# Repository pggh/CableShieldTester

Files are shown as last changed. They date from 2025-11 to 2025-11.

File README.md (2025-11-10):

# CableShieldTester

This is a simple build-it-yourself device that allows you to test
whether a cable is shielded or not. The device is easy and fast to use,
however, depending on the connector type you are dealing with, you need
a connector or adapter to get access to the signal lines.
There must be nothing connected to the other side of the cable.

The design is based on an ATtiny84 micro-controller so you will need a
programmer for it to build your device. (Any of the ATtiny24, ATtiny24A,
ATtiny44, ATtiny44A, ATtiny84, ATtiny84A will work.)

This video shows the test of an unshielded cable (**play with sound!**):

https://github.com/user-attachments/assets/809c1926-0d2f-4c97-92ae-36a32c1142be

More tests can be found [here](doc).

Build instructions are in the [hardware directory](hardware).

Discus at the [EEVblog Forum](https://www.eevblog.com/forum/projects/cableshieldtester-is-the-cable-shielded-or-not-(diy-project)/msg6097537/)

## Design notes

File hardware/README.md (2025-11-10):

# Hardware build instructions

There are two sets of schematics and PCBs:

- [template](template) contains the files you can use as a start
  to build your own device. The schematics and layout does not contain
  the power section, so you can choose what is suitable for your
  needs.  
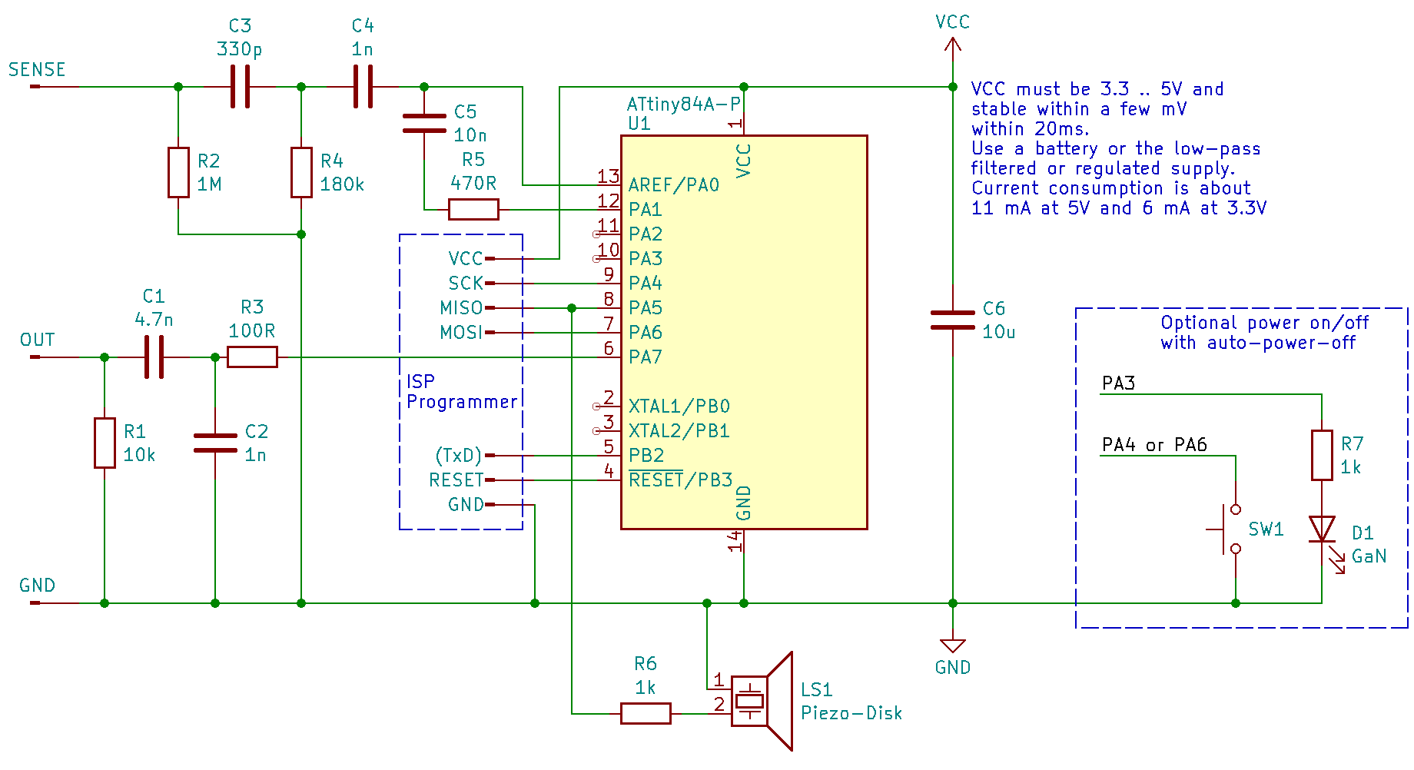
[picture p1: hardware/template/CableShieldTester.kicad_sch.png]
  [](template/CableShieldTester.kicad_sch.png)\
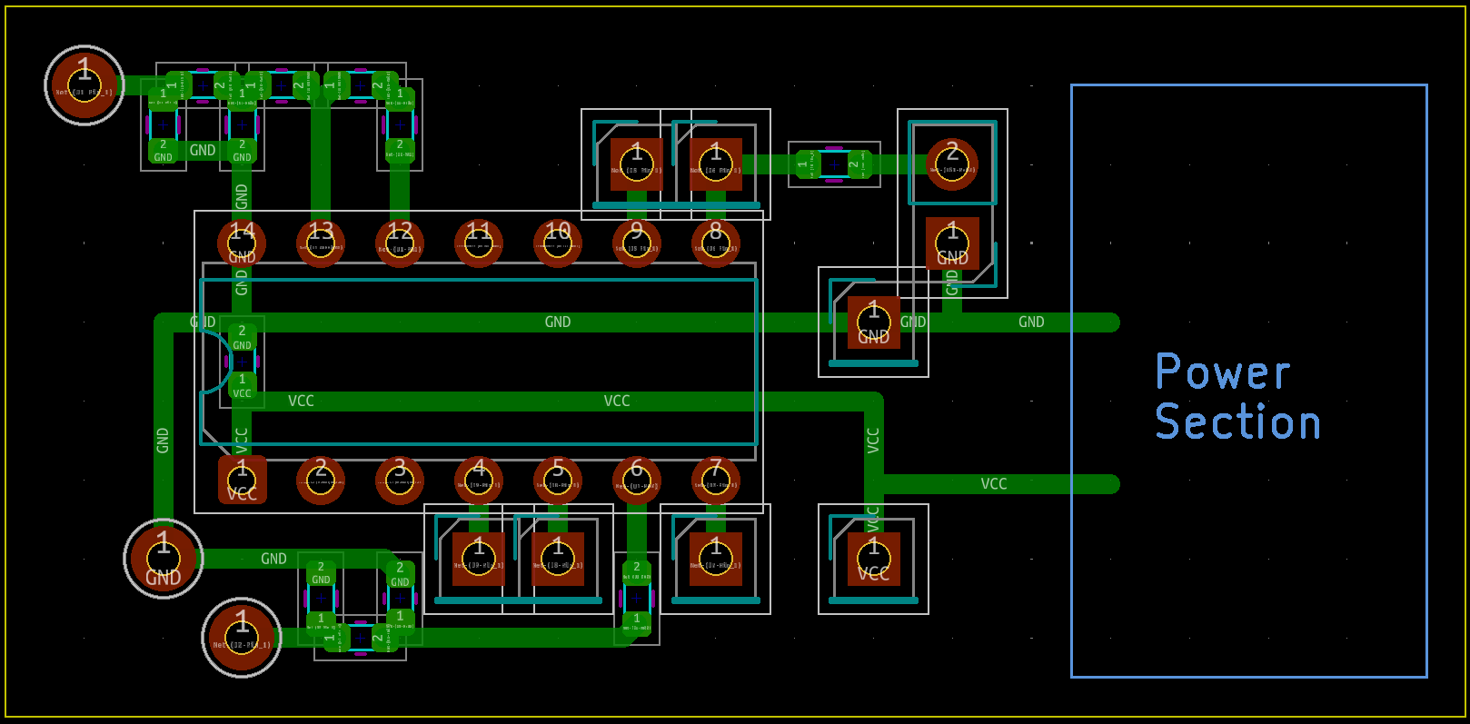
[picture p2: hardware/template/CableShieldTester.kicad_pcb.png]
  [](template/CableShieldTester.kicad_pcb.png)
- [my_build](my_build) contains the full schematics and layout of what I actually
  built for myself as a reference.  
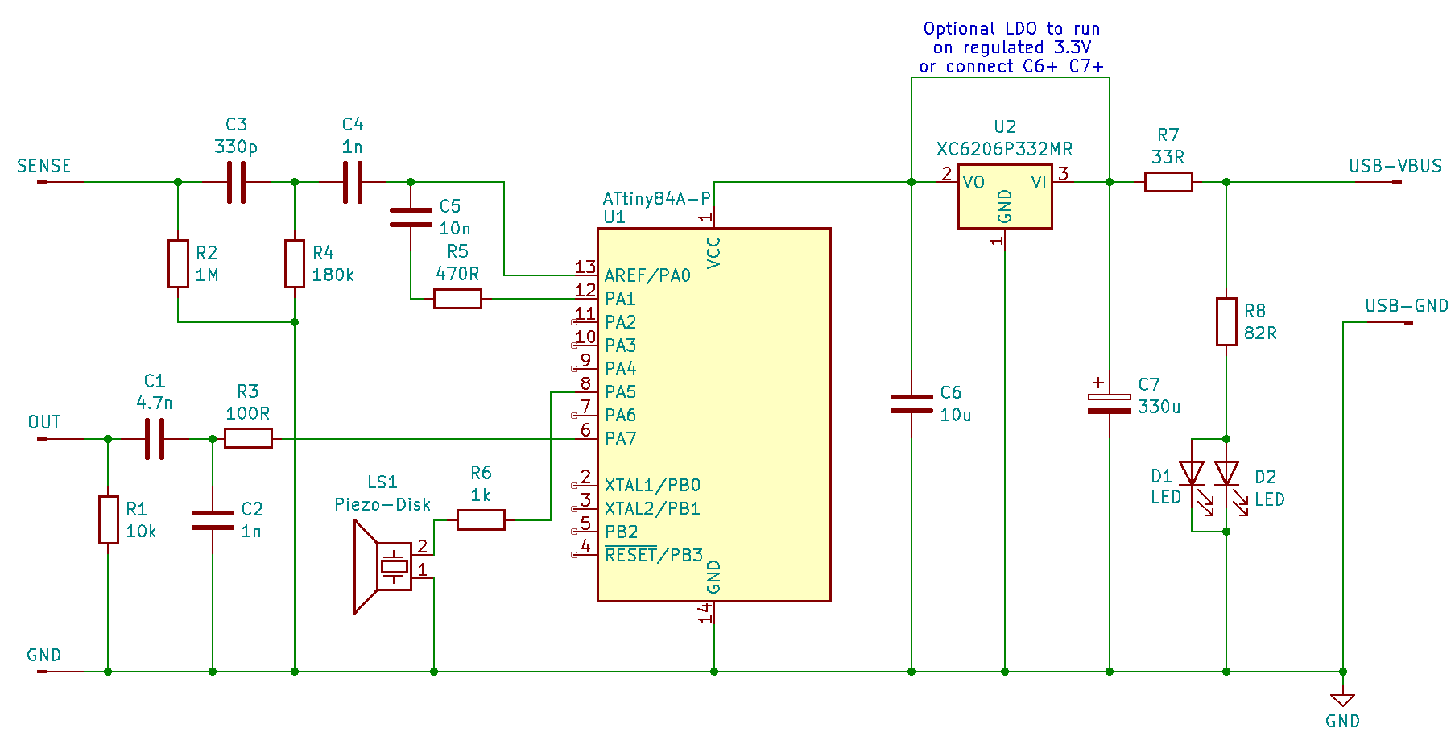
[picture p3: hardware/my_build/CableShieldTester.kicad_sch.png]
  [](my_build/CableShieldTester.kicad_sch.png)\
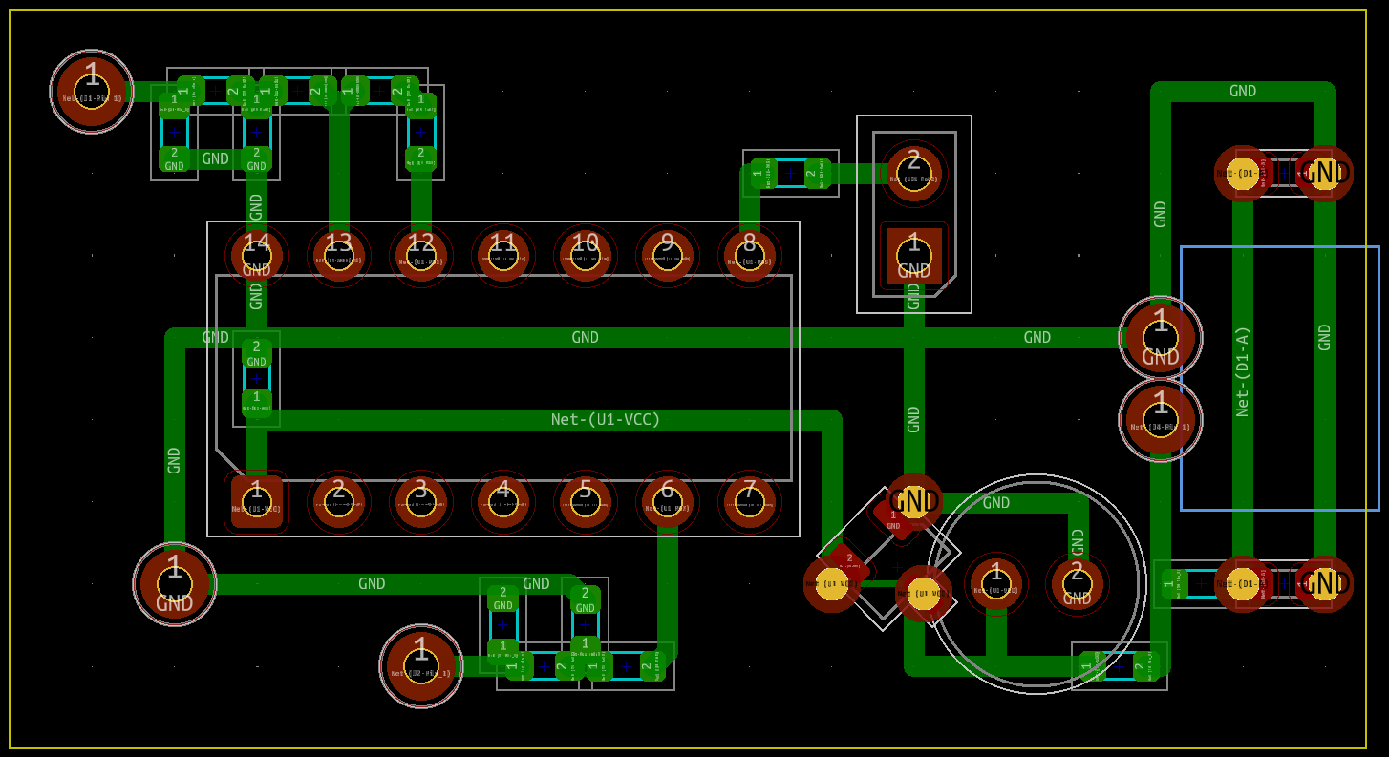
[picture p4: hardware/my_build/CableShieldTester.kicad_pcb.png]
  [](my_build/CableShieldTester.kicad_pcb.png)\
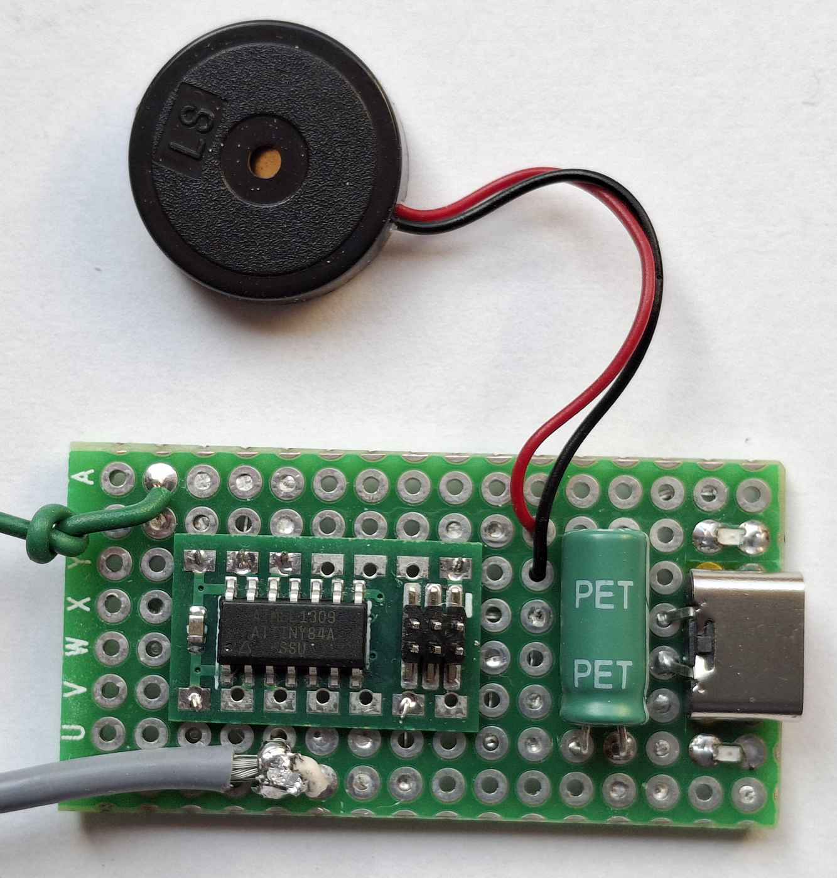
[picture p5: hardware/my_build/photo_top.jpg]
  [](my_build/photo_top.jpg)\
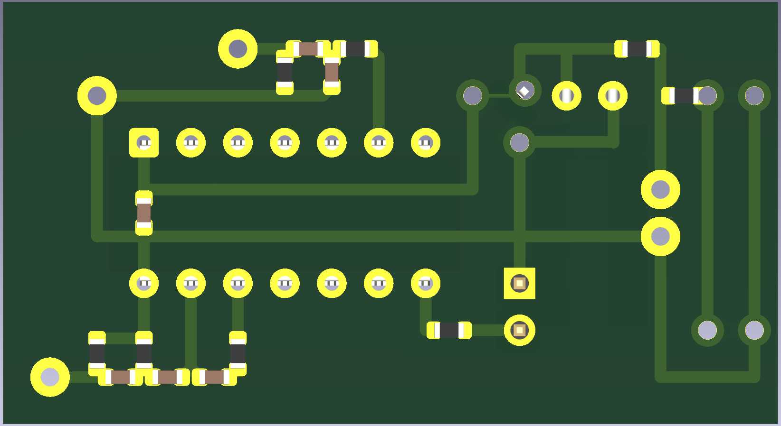
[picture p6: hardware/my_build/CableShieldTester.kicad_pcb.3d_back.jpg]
PCB back
  [](my_build/CableShieldTester.kicad_pcb.3d_back.jpg)\
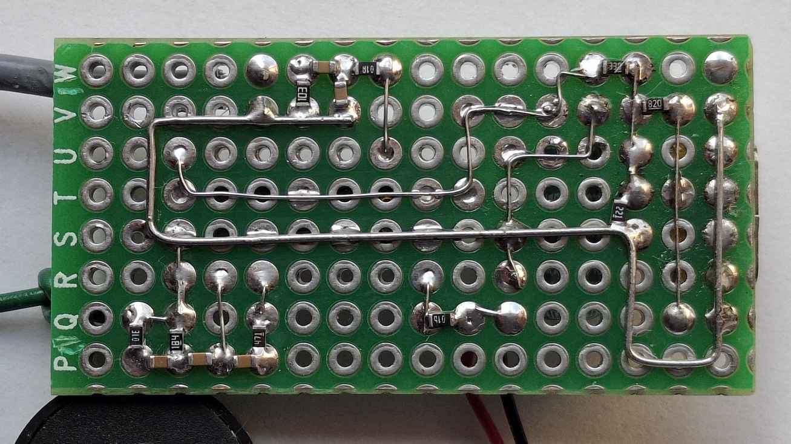
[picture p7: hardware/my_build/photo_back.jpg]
  [](my_build/photo_back.jpg)\
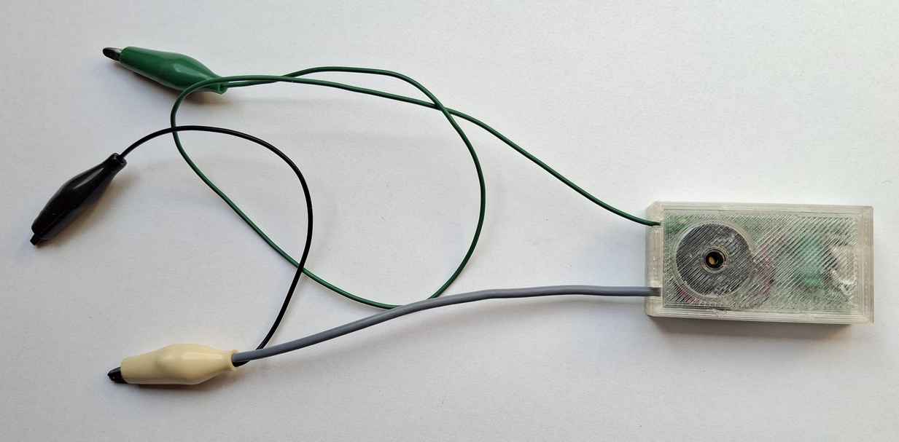
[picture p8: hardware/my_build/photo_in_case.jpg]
  [](my_build/photo_in_case.jpg)

# Layout and cables

- Keep output components and connection close to the Pin 6 and away form
  sense input.
- Use a shielded cable for the output signal. The shield (connected to
  GND) should go as close to the output components and the external
  output clip as possible. The GND clip can be connected to either side
  of the shield of the output cable.
- Keep sense input components and connection close to the input pins.
- Use a unshielded cable for the sense input to keep the input capacity
  low.

# Powering

The power source is critical. Due to the measurement principle of the
device, VCC must be rather stable within a measurement cycle of 20ms.

The ideal power source is a battery. A 3.6V lithium battery (non
rechargeable or rechargeable) or 3 AAA cells (alkaline or NiMH)

When using external power, the source should not have much ripple and a
proper voltage regulation. Many cheap USB chargers fail in both
disciplines. Also the power source must not have any mains common-mode
signal. Use either a power-bank or a mains power supply that has an
earth referenced output.

The usual 2 pin (mains) chargers have a Y2 capacitor from the mains to
the GND of the output and therefore a common-mode 50/60Hz signal of up
to 300Vpp. This is not acceptable for the high impedance measurement of
the cable tester and might even damage it.

When using power-banks, practically all modern ones require a minimal
load to stay on. I tested my build (consumes 43 mA with the two LEDs)
with 4 different power-banks a the current was sufficient for two of them
to stay on but not for the other two.

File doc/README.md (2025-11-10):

# Measurement examples

**Important: play all videos with sound - the measurement result is acoustical.**

## An unshielded audio cable

The ground pin is already connected. When the signal is applied to one of the audio lines, it is coupled to the sense line.

https://github.com/user-attachments/assets/809c1926-0d2f-4c97-92ae-36a32c1142be

## A shielded audio cable

The ground pin is already connected. When the signal is applied to one of the audio lines, nothing happens because the signal is shielded.

https://github.com/user-attachments/assets/3892af2c-89ef-467d-8cf5-392d25709fa2

## Common shield for both channels

The ground pin as well as the signal pin are already connected.
When connecting the sense input to the other audio channel, the signal is heavily coupled to it.

https://github.com/user-attachments/assets/de1b4ab3-1894-417e-95cb-727351e04f2a

## Individual shield for both channels

The ground pin as well as the signal pin are already connected.
When connecting the sense input to the other audio channel, the signal is slightly coupled to it.
Ideally no signal should leak through. The slight coupling could be within the connector or the shield is not that great.

https://github.com/user-attachments/assets/d68851f2-6222-4acf-88ee-22f93a323d15

## Unshielded USB cable

The signal pin is already connected to one of the USB signals. It is coupled to the sense line.
The coupling is not stopped, when connecting ground line to the shell of the connector.

https://github.com/user-attachments/assets/f3afa772-5d94-4523-8f89-95132691fe7d

## Shielded USB cable

The signal pin is already connected to one of the USB signals. It is coupled to the sense line.
When connecting the ground line to the shell of the connector, the signal coupling stops.

https://github.com/user-attachments/assets/339036e9-0693-466c-8054-61548ad63745

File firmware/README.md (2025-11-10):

# Firmware

This folder contains the sources and project files of the firmware.
It is meant to be compiled with 
[Atmel Studio / Microchip Studio for AVR](https://www.microchip.com/en-us/tools-resources/develop/microchip-studio#Downloads).
No particular framework is used, just the
[avr-libc](https://www.nongnu.org/avr-libc/user-manual/)
that comes with the AVR-GCC, so it should be possible to compile it
with other IDEs without much porting effort.

If you don't need any change, you can program the supplied
[.hex file](Release/CableShieldTester.hex)
and you don't need any compiler at all.

Many modification can be achieved by changing the definitions in
config.h. (Always use Release and not Debug builds)

Whether you use the supplied .hex file or you compile yourself,
I suggest that you set BOD fuses of the chip to a level of 2.7V.

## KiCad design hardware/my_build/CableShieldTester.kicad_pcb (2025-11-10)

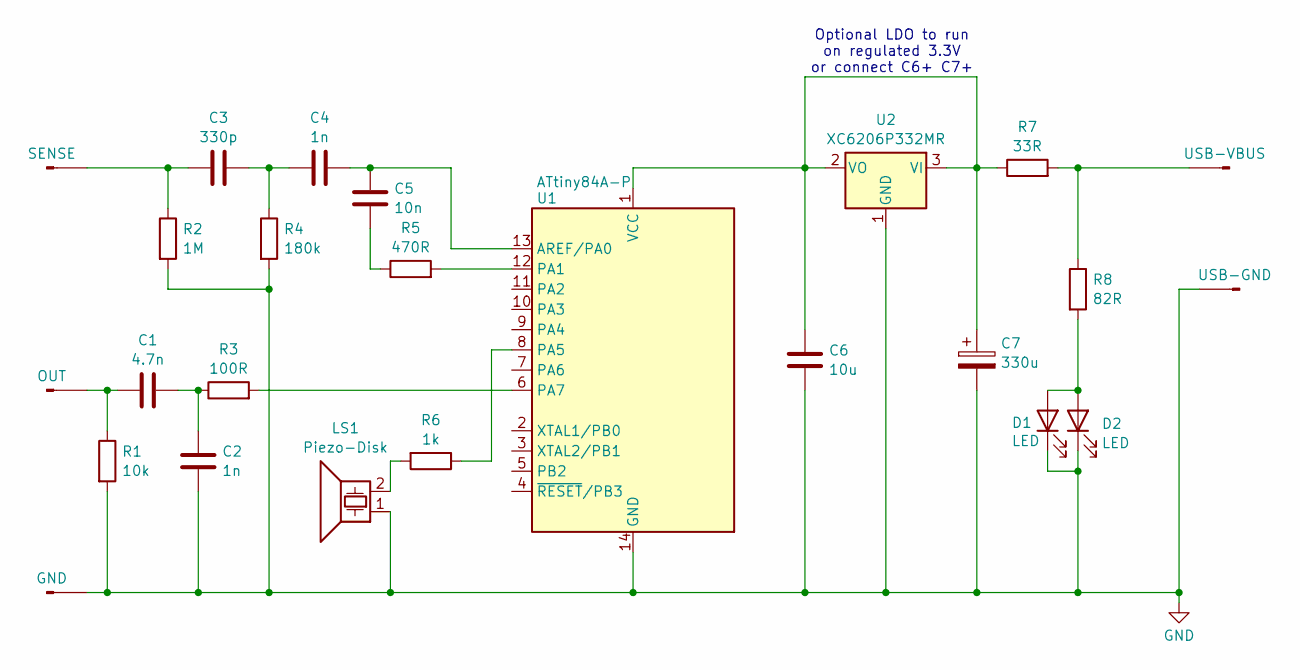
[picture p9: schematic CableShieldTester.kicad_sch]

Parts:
C1: 4.7n; C_0603_1608Metric
C2, C4: 1n; C_0603_1608Metric
C3: 330p; C_0603_1608Metric
C5: 10n; C_0603_1608Metric
C6: 10u; C_0603_1608Metric
C7: 330u; C_Radial_D6.3mm_H11.0mm_P2.50mm
D1, D2: LED; LED_0603_1608Metric
J1: SENSE; Pad_84mil
J2: OUT; Pad_84mil
J3: GND; Pad_84mil
J4: USB-VBUS; Pad_84mil
J5: USB-GND; Pad_84mil
LS1: Piezo-Disk; PinHeader_1x02_P2.54mm_Vertical
R1: 10k; R_0603_1608Metric
R2: 1M; R_0603_1608Metric
R3: 100R; R_0603_1608Metric
R4: 180k; R_0603_1608Metric
R5: 470R; R_0603_1608Metric
R6: 1k; R_0603_1608Metric
R7: 33R; R_0603_1608Metric
R8: 82R; R_0603_1608Metric
U1: ATtiny84A-P; DIP-14_W7.62mm
U2: XC6206P332MR; SOT-23-3

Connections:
GND: C2.2, C6.2, C7.2, D1.1 (K), D2.1 (K), J3.1, J5.1, LS1.1, R1.2, R2.2, R4.2, U1.14 (GND), U2.1 (GND)
unnamed: C1.2, C2.1, R3.1
unnamed: C3.2, C4.1, R4.1
unnamed: C5.2, R5.1
unnamed: D1.2 (A), D2.2 (A), R8.2
unnamed: C3.1, J1.1, R2.1
unnamed: C1.1, J2.1, R1.1
unnamed: J4.1, R7.2, R8.1
unnamed: LS1.2, R6.2
unnamed: C4.2, C5.1, U1.13 (AREF/PA0)
unnamed: R5.2, U1.12 (PA1)
unnamed: R6.1, U1.8 (PA5)
unnamed: R3.2, U1.6 (PA7)
unnamed: C6.1, C7.1, R7.1, U1.1 (VCC), U2.2 (VO), U2.3 (VI)

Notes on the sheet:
Optional LDO to run on regulated 3.3V or connect C6+ C7+

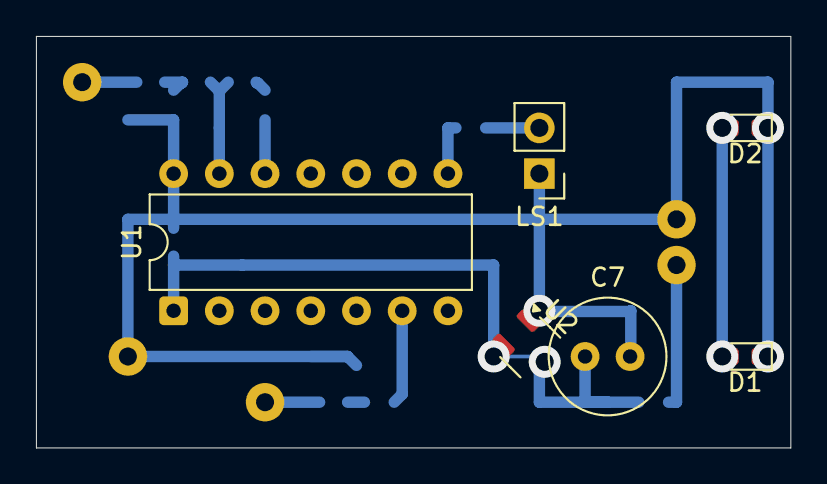
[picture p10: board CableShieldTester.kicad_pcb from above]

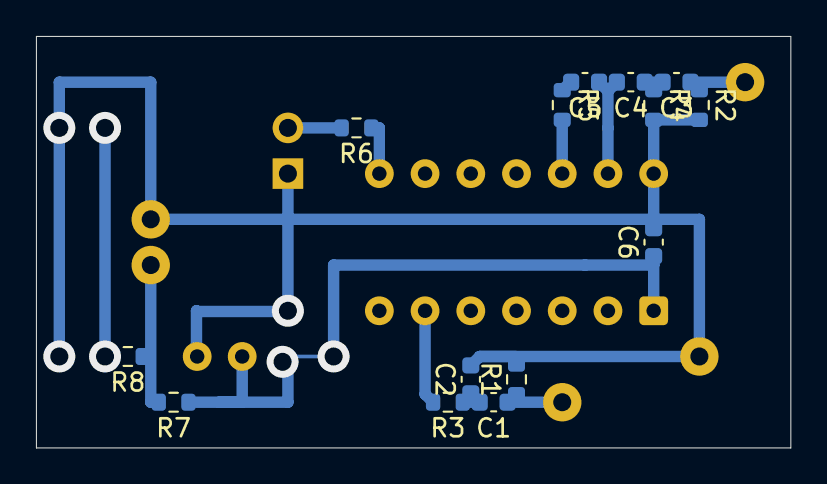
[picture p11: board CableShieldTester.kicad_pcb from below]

Board: 2 copper layers, 41.9 x 22.9 mm, 25 parts (14 on the bottom side), 14 nets.

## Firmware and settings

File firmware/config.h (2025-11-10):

#pragma once

#define F_CPU 8000000

// note: if you get a compilation error about constexpr, add --std=c++17 to the compiler arguments

constexpr double   signal_period_sec = 8.0 / F_CPU;
constexpr double   measure_duration_sec = 1.0 / 50.0; // 1/50 for 50Hz countries, 1/60 for 60Hz countries
constexpr uint16_t measure_signal_cycles = static_cast<uint16_t>(measure_duration_sec / signal_period_sec);
constexpr uint8_t  measure_phase = 7;

constexpr double   auto_power_off_sec = 300;
static_assert(auto_power_off_sec / measure_duration_sec <= 65535, "auto_power_off_sec too long.");
constexpr uint16_t power_off_measure_count = static_cast<uint16_t>(auto_power_off_sec / measure_duration_sec);

/*
PIN  1  VCC
PIN  2  PB0 INIT=OUT0
PIN  3  PB1 INIT=OUT0
PIN  4  PB3 INIT=IN   PORG-RESET
PIN  5  PB2 INIT=OUT1 (SERIAL)
PIN  6  PA7 INIT=OUT0           OC0B/GEN-OUT
PIN  7  PA6 INIT=IN   PROG-MOSI (Power-Button)
PIN  8  PA5 INIT=OUT0 PROG-MISO OC1B/BEEP-OUT
PIN  9  PA4 INIT=IN   PROG-SCK  (Power-Button)
PIN 10  PA3 INIT=OUT0           (Power-On-LED)
PIN 11  PA2 INIT=OUT0
PIN 12  PA1 INIT=OUT            SENSE_B
PIN 13  PA0 INIT=OUT            SENSE_A
PIN 14  GND
*/

#define INIT_PORTA             0b0101'0000
#define INIT_DDRA              0b1010'1111
#define INIT_PORTB             0b0000'1100
#define INIT_DDRB              0b0000'0111

// PIN must be OC0B = PA7
#define PIN_GENOUT_PORT        PORTA
#define PIN_GENOUT_DDR         DDRA
#define PIN_GENOUT_BIT         7
#define PIN_GENOUT_MASK        (1<<PIN_GENOUT_BIT)

// PIN must be OC1B = PA5
#define PIN_SPEAKER_PORT       PORTA
#define PIN_SPEAKER_DDR        DDRA
#define PIN_SPEAKER_BIT        5
#define PIN_SPEAKER_MASK       (1<<PIN_SPEAKER_BIT)

#define PIN_SENSE_PORT         PORTA
#define PIN_SENSE_DDR          DDRA
#define PIN_SENSE_A_BIT        0
#define PIN_SENSE_A_MASK       (1<<PIN_SENSE_A_BIT)
#define PIN_SENSE_B_BIT        1
#define PIN_SENSE_B_MASK       (1<<PIN_SENSE_B_BIT)
#define PIN_SENSE_B_ADMUX      1

#define PIN_PWRLED_PORT        PORTA
#define PIN_PWRLED_DDR         DDRA
#define PIN_PWRLED_BIT         3
#define PIN_PWRLED_MASK        (1<<PIN_PWRLED_BIT)

#define PIN_PWRBUTTON_PIN      PINA
#define PIN_PWRBUTTON_PORT     PORTA
#define PIN_PWRBUTTON_DDR      DDRA
#define PIN_PWRBUTTON_MASK     0b0101'0000

//#define SERIAL_OUT
// when using SERIAL_OUT, the files ATtinySerialOut.h and ATtinySerialOut.hpp
// from https://github.com/ArminJo/ATtinySerialOut/tree/v2.3.1/src must be placed
// into the source directory and the "#include <Arduino.h>" must be removed from
// ATtinySerialOut.h.
// Also note that ATtinySerialOut does not support the ATtinyX4A, just the non-A versions
// ATtinyX4. Use that type for building the project; it works with the A chips as well.

//#define SERIAL_PHASE_TEST
// used during development to determine the phase value that results is the largest signal.

#ifdef SERIAL_OUT

#define PIN_TX_PORT            PORTB
#define PIN_TX_DDR             DDRB
#define PIN_TX_BIT             2
#define PIN_TX_MASK            (1<<PIN_TX_BIT)
#define PIN_TX_ARDUINO         10

constexpr bool SERIAL_OUT_ON_SPEAKER_PIN = &PIN_SPEAKER_PORT == &PIN_TX_PORT && PIN_SPEAKER_BIT == PIN_TX_BIT;

#else

constexpr bool SERIAL_OUT_ON_SPEAKER_PIN = false;

#endif

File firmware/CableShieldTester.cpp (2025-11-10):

#include <avr/io.h>
#include <avr/interrupt.h>
#include <avr/sleep.h>

#include "config.h"

#include <util/delay.h>

#ifdef SERIAL_OUT

#define digitalPinToPCMSKbit(p) (p&7)
#define TX_PIN PIN_TX_ARDUINO
#include <stdlib.h>
#include <avr/pgmspace.h>
#include "ATtinySerialOut.hpp"

#endif

void set_no_beep()
{
   OCR1B = 0xFFFF;
   OCR1A = 1;
}

void set_beep_freq(uint16_t f)
{
   constexpr uint32_t base_freq = F_CPU / 64;
   static_assert(base_freq >= 0xFFFFu, "timer calculation assumes base_freq >= 65535 Hz");
   if (f < (base_freq+65535)>>16) {
      set_no_beep();
      } else {
      auto div = base_freq / f;
      OCR1B = (div>>1)-1;
      OCR1A = div-1;
   }
}

void bbtest_no_dead_time(uint8_t phase/*r24*/, uint16_t count/*r23:r22*/)
{
   asm volatile
   (
   "in   r20, %[oreg] \n\t"
   "andi r20, ~(%[ma] | %[mb]) \n\t"
   "mov  r18, r20     \n\t"
   "ori  r18, %[ma]   \n\t"
   "mov  r19, r20     \n\t"
   "ori  r19, %[mb]   \n\t"

   "out %[tcreg], r24 \n\t"

   "loop1:            \n\t"
   "out %[oreg], r18  \n\t" // 1 cycle
   "nop               \n\t" // 1 cycle
   "subi r22, 1       \n\t" // 1 cycle
   "sbc  r23, r1      \n\t" // 1 cycle
   "out %[oreg], r19  \n\t" // 1 cycle
   "nop               \n\t" // 1 cycle
   "brne loop1        \n\t" // 2 cycles

   "out %[oreg], r20  \n\t"
   :
   :
   [oreg]  "I" _SFR_IO_ADDR(PIN_SENSE_DDR),
   [ma]    "I" PIN_SENSE_A_MASK,
   [mb]    "I" PIN_SENSE_B_MASK,
   [tcreg] "I" _SFR_IO_ADDR(TCNT0)
   :
   );
}

void bbtest_with_dead_time(uint8_t phase/*r24*/, uint16_t count/*r23:r22*/)
{
   asm volatile
   (
   "in   r20, %[oreg] \n\t"
   "andi r20, ~(%[ma] | %[mb]) \n\t"
   "mov  r18, r20     \n\t"
   "ori  r18, %[ma]   \n\t"
   "mov  r19, r20     \n\t"
   "ori  r19, %[mb]   \n\t"

   "out %[tcreg], r24 \n\t"

   "loop2:            \n\t"
   "out %[oreg], r20  \n\t" // 1 cycle
   "out %[oreg], r18  \n\t" // 1 cycle
   "subi r22, 1       \n\t" // 1 cycle
   "sbc  r23, r1      \n\t" // 1 cycle
   "out %[oreg], r20  \n\t" // 1 cycle
   "out %[oreg], r19  \n\t" // 1 cycle
   "brne loop2        \n\t" // 2 cycles

   "out %[oreg], r20  \n\t"
   :
   :
   [oreg]  "I" _SFR_IO_ADDR(PIN_SENSE_DDR),
   [ma]    "I" PIN_SENSE_A_MASK,
   [mb]    "I" PIN_SENSE_B_MASK,
   [tcreg] "I" _SFR_IO_ADDR(TCNT0)
   :
   );
}

void prepare_measure()
{
   // SENSE_A output HIGH
   // SENSE_B output LOW
   PIN_SENSE_PORT |= PIN_SENSE_A_MASK;
   PIN_SENSE_PORT &= ~PIN_SENSE_B_MASK;
   PIN_SENSE_DDR |= (PIN_SENSE_A_MASK | PIN_SENSE_B_MASK);

   // wait 50us for Cap to charge to VDD
   _delay_us(50);

   // SENSE_A open
   // SENSE_B open
   MCUCR |= _BV(PUD); // disable pull-up
   PIN_SENSE_DDR &= ~(PIN_SENSE_A_MASK | PIN_SENSE_B_MASK);
}

uint16_t get_measure_result()
{
   // SENSE_A output HIGH, SENSE_B left floating
   PIN_SENSE_DDR |= PIN_SENSE_A_MASK;
   ADMUX = PIN_SENSE_B_ADMUX;
   ADCSRA |= _BV(ADSC);
   while (ADCSRA & _BV(ADSC)) {}
   ADMUX = 0b100000; // GND input
   MCUCR &= ~_BV(PUD); // enable pull-up
   return ADC;
}

uint16_t measure(uint8_t phase, bool dt)
{
   prepare_measure();
   if (dt) {
      bbtest_with_dead_time(phase, measure_signal_cycles);
   } else {
      bbtest_no_dead_time(phase, measure_signal_cycles);
   }
   return get_measure_result();
}

void do_measure()
{
   auto m = measure(measure_phase, true);
   set_beep_freq(8*m);
#ifdef SERIAL_OUT
   Serial.print(m);
   Serial.print("\r\n");
#endif
}

#ifdef PIN_PWRBUTTON_MASK

ISR(PCINT0_vect) {}
ISR(PCINT1_vect) {}

inline bool power_button_pressed()
{
   return (PIN_PWRBUTTON_PIN & PIN_PWRBUTTON_MASK) != PIN_PWRBUTTON_MASK;
}

bool power_button_press()
{
   static bool was_pressed = false;
   bool pressed = power_button_pressed();
   auto ret = pressed & !was_pressed;
   was_pressed = pressed;
   return ret;
}

void power_off()
{
   // all ports to init state
   PORTA = INIT_PORTA;
   DDRA = INIT_DDRA;
   PORTB = INIT_PORTB;
   DDRB = INIT_DDRB;
   // timer output off
   TCCR0A &= ~(_BV(COM0B1) | _BV(COM0B0));
   TCCR1A &= ~(_BV(COM1B1) | _BV(COM1B0));
   // ADC off
   ADCSRA = 0;

   // end sleep on pin-change
   if (&PIN_PWRBUTTON_PORT == &PORTA) {
      GIMSK = _BV(PCIE0);
      PCMSK0 = PIN_PWRBUTTON_MASK;
   } else {
      GIMSK = _BV(PCIE1);
      PCMSK1 = PIN_PWRBUTTON_MASK;
   }

   // wait for button release with debounce
   for(uint8_t i = 0; i < 10; ++i) {
      if (power_button_pressed()) {
         i = 0;
      } else {
         _delay_ms(1);
      }
   }

   set_sleep_mode(SLEEP_MODE_PWR_DOWN);
   sleep_enable();
   sleep_bod_disable();
   sleep_cpu();
   sleep_disable();

   // no pin change interrupts any more
   GIMSK = 0;

   // debounce
   _delay_ms(10);

   // consume "press" of power-on
   power_button_press();
}

#endif

int main(void)
{
   // switch to 8 MHz
   CLKPR = 0x80;
   CLKPR = 0;

   MCUCR |= _BV(BODS) | _BV(BODSE);


#ifdef PIN_PWRBUTTON_MASK
   // do not handle auto-power-off after getting external power, only use
   // power-button to switch off. This allows to use the same code for
   // devices with and without power-button.
   bool first_power_on = true;
#endif
   sei();

   for(;;) {
      DIDR0 = PIN_SENSE_A_MASK | PIN_SENSE_B_MASK;
      PORTA = INIT_PORTA;
      DDRA = INIT_DDRA;
      PORTB = INIT_PORTB;
      DDRB = INIT_DDRB;

#ifdef PIN_PWRLED_MASK
      PORTA |= PIN_PWRLED_MASK;
#endif
#ifdef SERIAL_OUT
      initTXPin();
#endif

      // ADC
      ADMUX = 0b100000; // GND input
      ADCSRA = _BV(ADEN) | _BV(ADPS2) | _BV(ADPS1); // ADC clock = CPU / 64 = 125 kHz
      ADCSRB = 0;

      // init Timer0 Fast PWM Mode with TOP = OCR0A
      TCNT0 = 0;
      OCR0A = 7;
      OCR0B = 3;
      TCCR0A = _BV(COM0B1) | _BV(WGM01) | _BV(WGM00);
      TCCR0B = _BV(WGM02) | _BV(CS00);

      // init Timer1 Fast PWM with TOP = OCR1A, clock = FCPU/64
      TCNT1 = 0;
      set_no_beep();
      if (SERIAL_OUT_ON_SPEAKER_PIN) {
         TCCR1A =                             _BV(WGM11) | _BV(WGM10);
      } else {
         TCCR1A = _BV(COM1B1) | _BV(COM1B0) | _BV(WGM11) | _BV(WGM10);
      }
      TCCR1B = _BV(WGM13) | _BV(WGM12) | _BV(CS11) | _BV(CS10);


#ifdef SERIAL_PHASE_TEST
      for(;;) {
         Serial.print("\r\n\r\nNDT");
         for(uint8_t p = 0; p <= 7; ++p) {
            Serial.print(" P");
            Serial.print((char)('0'+p));
            Serial.print(' ');
            Serial.print(measure(p, false));
         }
         _delay_ms(100);
         Serial.print("\r\nDT ");
         for(uint8_t p = 0; p <= 7; ++p) {
            Serial.print(" P");
            Serial.print((char)('0'+p));
            Serial.print(' ');
            Serial.print(measure(p, true));
         }
         _delay_ms(500);
      }
#endif

#ifdef PIN_PWRBUTTON_MASK

      if (first_power_on) {
         first_power_on = false;
         do {
            do_measure();
         } while (!power_button_press());
      } else {
         for(uint16_t auto_off_countdown = power_off_measure_count; auto_off_countdown != 0 && !power_button_press(); --auto_off_countdown) {
            do_measure();
         }
      }
      power_off();

#else

      for(;;) {
         do_measure();
      }

#endif
   }
}
